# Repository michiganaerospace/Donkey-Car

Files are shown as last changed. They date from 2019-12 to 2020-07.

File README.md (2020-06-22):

# Donkey-Car
The Donkey Car is a remote/self driving RC car project which runs on a Raspberry Pi. We have created some documentation (Donkey RC Car Setup.docx) on how to assemble the Donkey Car that needs to be completed. In this github there is a group of solidworks/stl files that can be used to 3d print parts required to make the Donkey Car. The donkey car docs file has a link to a website with extensive documentation on the Donkey Car. There is a large ammount of additional info at http://docs.donkeycar.com/ , so check it out.
 


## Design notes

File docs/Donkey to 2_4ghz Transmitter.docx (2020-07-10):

## Donkey Car: Pi to 2.4 G RC Transmitter

## To switch from using the Logitech controllers and the Raspberry Pi to using the 2.4 G RC Transmitter (given in the package) use the following steps:

## 1) Make sure the car is off (bottom battery unplugged)

## 2) Unplug the wires from the motor controller and plug them into the receiver near the bottom of the car as shown.

## = steering cable – from channel 0 to channel 2

## = throttle cable – from channel 1 to channel 1

Receiver

Motor Controller

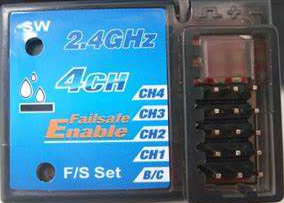
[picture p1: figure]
See the source image
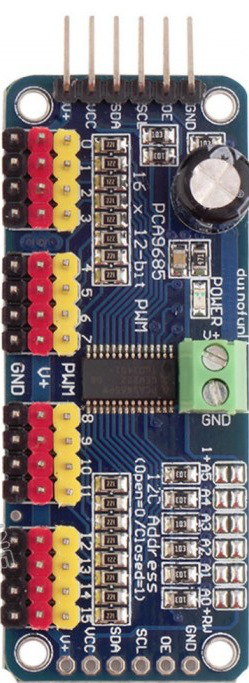
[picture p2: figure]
See the source image
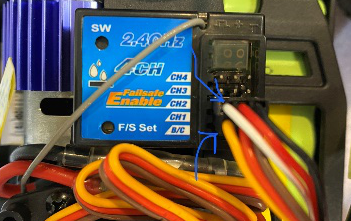
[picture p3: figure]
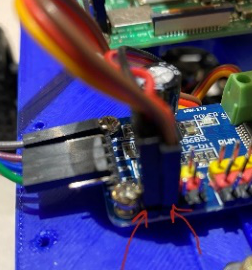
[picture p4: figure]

## 3) Plug the bottom battery pack back in and lights should come on on both the ESC and the receiver. Then take the controller for that designated car and open the top panel to access the on/off switch. Turn it on and you’re ready to go

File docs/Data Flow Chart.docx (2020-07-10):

Data-Flow Diagrams for RC Mode – Pi

During setup

Driver uses PuTTY/Terminal/App to SSH into the Raspberry Pi

Driver uses the RPi terminal to execute the drive command

The drive command enables a web browser that will allow the user to control certain settings of the car and see through the camera

During Driving

Pi receives that signal and sends it through the motor controller, which results in the vehicle driving!

Nano-receiver sends that signal to the laptop through USB port

Controller sends that joystick signal to its respective nano-receiver

Driver moves the joystick

Laptop sends that signal through to the SSH session controlling the Pi and to the web browser

During Training

Driver drives around track, collecting data in the form of photos and values that are put into a folder, or “tub”

With a “drive model” command, the car begins driving, using the model as a reference for how it should respond to the environment or “track”

This “model” is transferred back to the Pi via USB or SSH commands

With a “train” command, the laptop takes and analyzes the data to create a model of how the car should run based on your movements

The “tub” of data is transferred from the Pi to the laptop via Filezilla, USB memory stick, or SSH commands

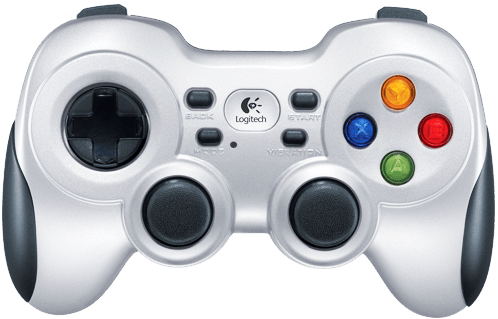
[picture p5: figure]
See the source image
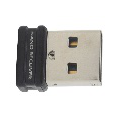
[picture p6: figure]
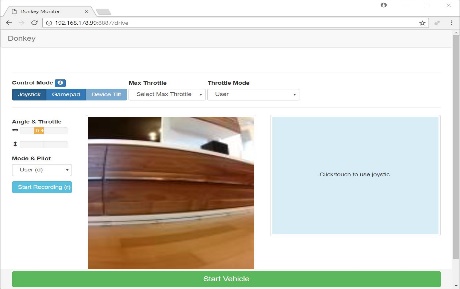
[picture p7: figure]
See the source image
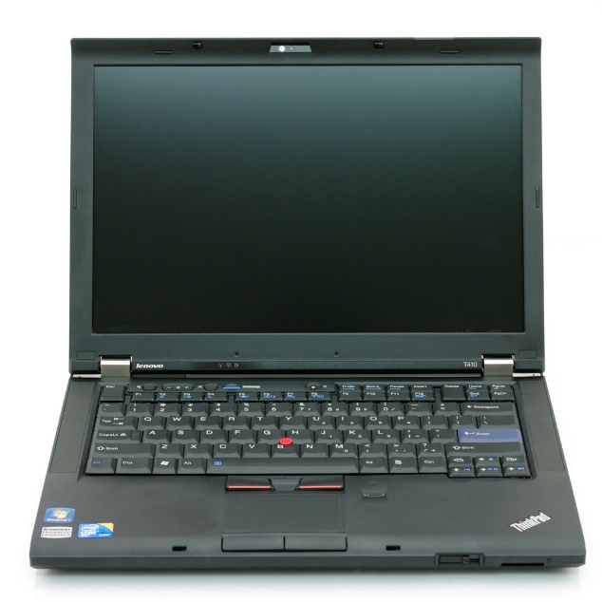
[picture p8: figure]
See the source image
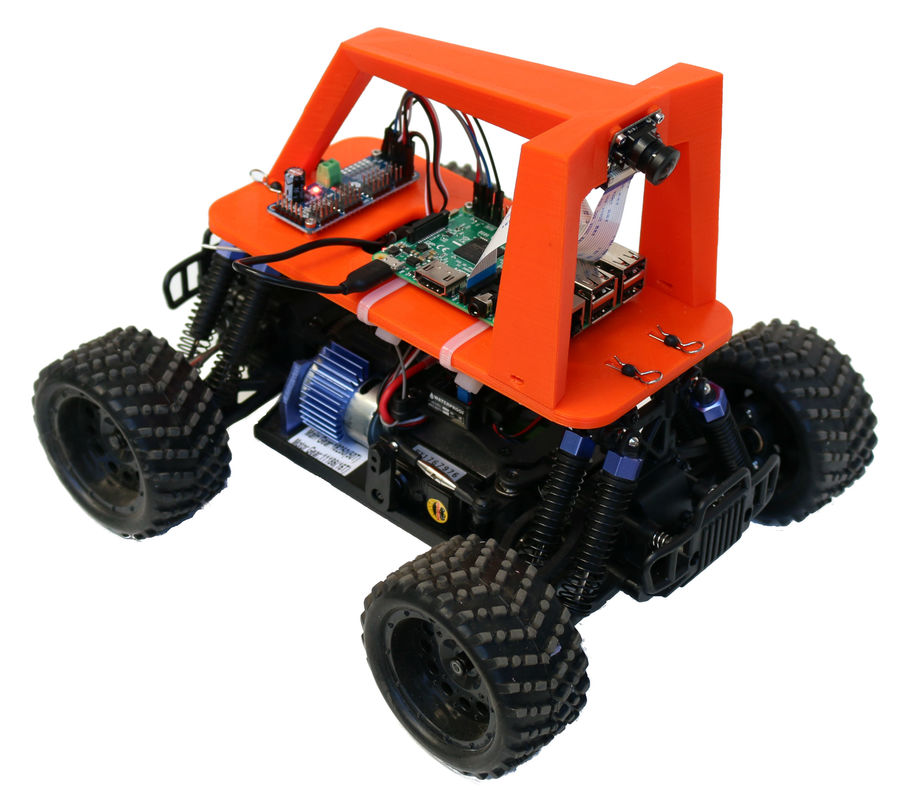
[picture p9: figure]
See the source image
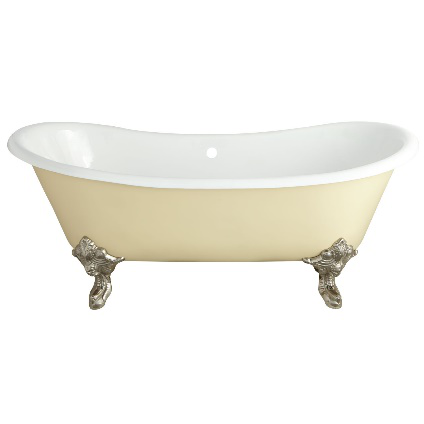
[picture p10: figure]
See the source image
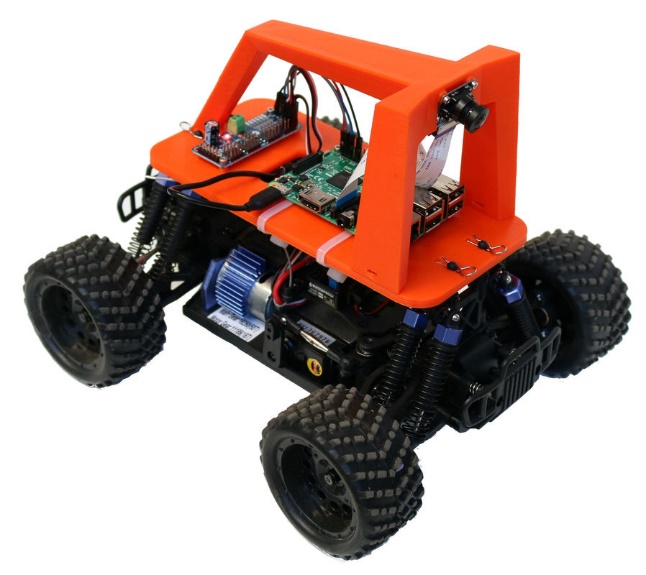
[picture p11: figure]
See the source image
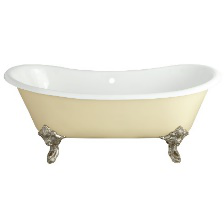
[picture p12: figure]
See the source image
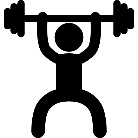
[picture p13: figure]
See the source image
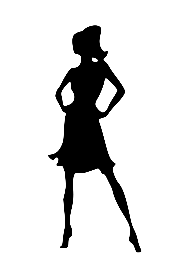
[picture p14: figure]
See the source image
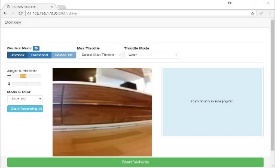
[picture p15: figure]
See the source image
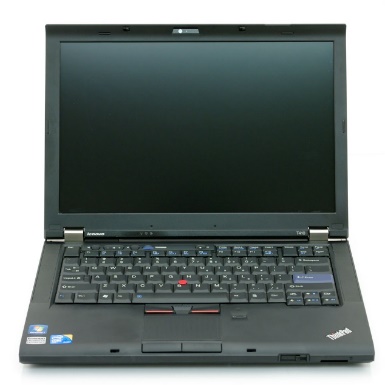
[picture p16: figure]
See the source image

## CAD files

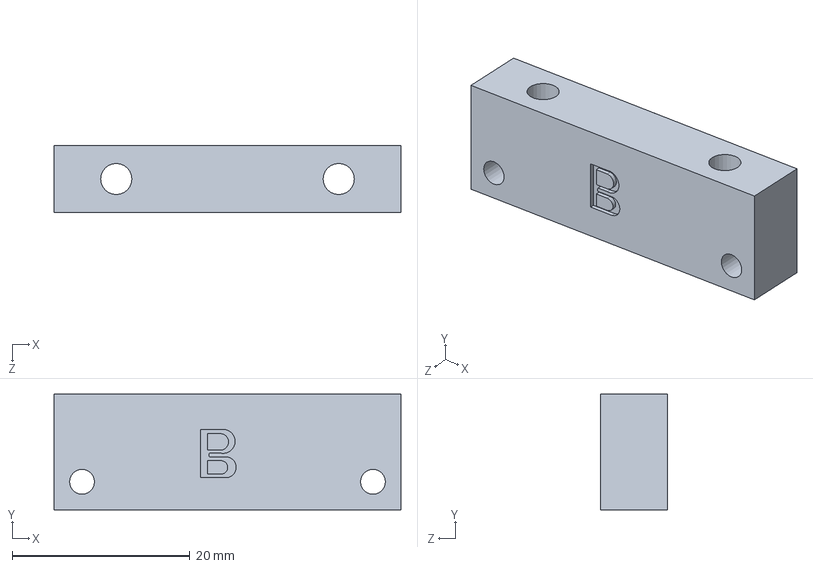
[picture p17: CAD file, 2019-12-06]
3d parts/new back adapter.SLDPRT
39.0 x 13.0 x 7.50 mm

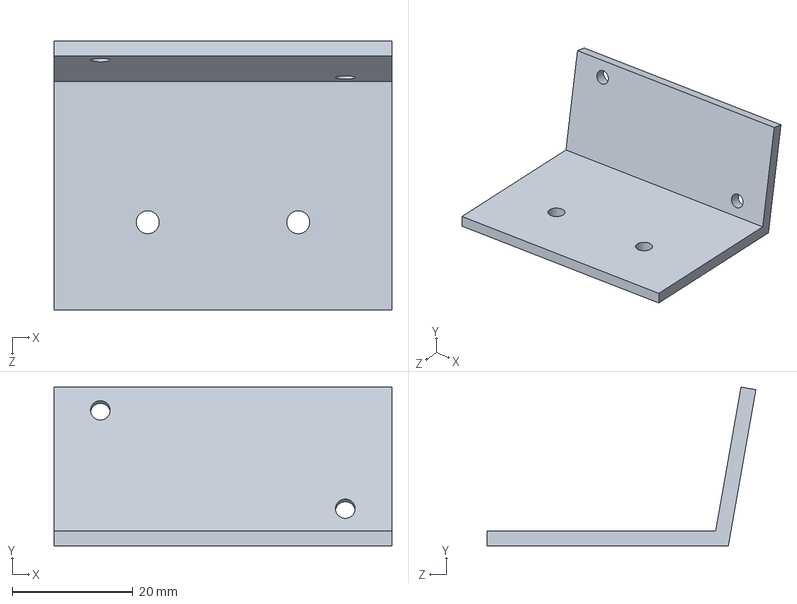
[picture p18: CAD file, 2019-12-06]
3d parts/ping sensor mount v5.SLDPRT
55.9 x 26.3 x 44.4 mm

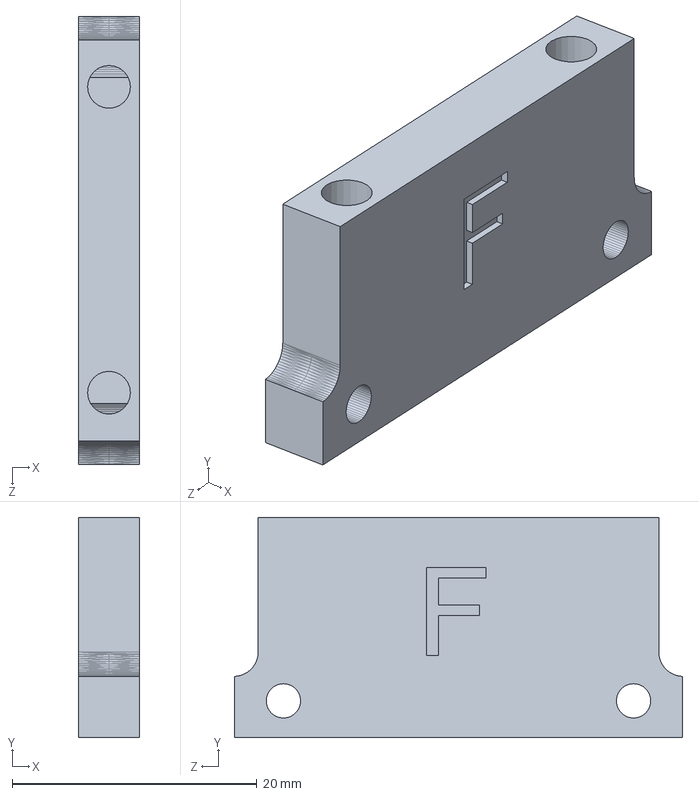
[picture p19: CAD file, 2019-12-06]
3d parts/new front NEW.SLDPRT
5.00 x 18.0 x 36.6 mm

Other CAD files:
3d parts/new back adapter.STL
3d parts/new front NEW.STL

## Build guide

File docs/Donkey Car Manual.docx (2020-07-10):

## Donkey Car Manual

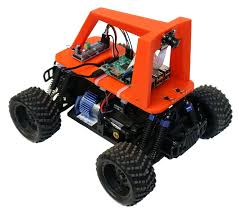
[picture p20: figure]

SD Card Formatting, Powering Up, Wi-Fi Setup……..…………. 2

Connecting to Pi……………………………………………………………….. 2

Driving…………………………………………………………………………….. 3

Training…………………………………………………………………………… 5

Part List……………………………………………………………………………. 8

Printing Parts……………………………………………………………………. 9

Software Install………………………………………………………………… 9

Creating the Car App………………………………………………………… 12

Calibration……………………………………………………………………….. 13

About: Raspbian is the Raspberry Pi Operating System and Balena Etcher is an SD card formatter

# SD Card Formatting

## On a PC, download the latest version of Raspbian, as well as Balena Etcher. Select the Raspbian image and your SD card. Click ‘flash’ to start formatting the SD card. Once the card is formatted, you can slide it into the small SD card slot on the underside of the Raspberry Pi (located at the front).

# Powering up the Donkey Car

To turn on the donkey car you will need two batteries. One is a Ni-MH battery that fits into the bottom slot of the donkey car and has some pins that hold it in. There is a small connector right by the slot that the Ni-MH battery will plug into. In order to power the Pi, there is a Li-Po battery pack which will plug into the Pi thru a USB to micro USB cable. Once you have these two batteries plugged in the donkey car will be ready to roll or setup.

# Setup the Wi-Fi Connection for Pi

To setup Wi-Fi access to the donkey car you will want to power up the Pi on the vehicle. Connect the Pi to a monitor thru the HDMI port on the Pi and plug in a USB mouse and keyboard. Click on the Wi-Fi icon in the top right corner of the Raspberry Pi screen. Select your network and put in the password if necessary

About: The Raspberry Pi is a microcomputer with many different capabilities and applications

# Connecting to the Pi

About: SSH (Secure Shell) is a way to access another computer over a network

## If you followed the above instructions to add Wi-Fi access, your Pi should now be connected to your Wi-Fi network. Now you need to find its IP address so you can connect to it via SSH.

To find the IP address, you will want to plug in an HDMI monitor and USB keyboard/mouse into the Pi, if it isn’t already. Boot it. Login with:

About: An IP address is a string of numbers that are used to identify individual computers and devices

- Username: pi
- Password: 1234

Then try the command in the Pi terminal:

About: A terminal (aka console, command line) is an application in which the user can execute commands directly

ifconfig wlan0

## If this has a valid IPv4 address, 4 groups of numbers separated by dots, then you can try that with your SSH command. If you don't see anything like that, then your Wi-Fi config might have a mistake. You can try to fix with:

Tip: You can also use the Network Analyzer app on your phone to find the IP address of the Pi on the network

sudo nano /etc/wpa_supplicant/wpa_supplicant.conf

In the Pi terminal, type:

ping raspberrypi.local or ping pi-<your car number>.local

Hopefully, one of those methods worked and you have the IP address. On Mac and Linux, you can open Terminal. On Windows, use PuTTY, or on Windows 10 you may have SSH via the command prompt.

Tip: On most computers, you will want to use the PuTTY app to SSH. See the Quick Start Guide for more details on SSH’ing with PuTTY.

If you have a command prompt, you can try:

ssh pi@raspberrypi.local

or ssh pi@<your pi ip address>

About: PuTTY is an open source software that enables users to use different network protocols, such as SSH.

# Drive your car

If you are not already, please SSH into your vehicle (http://docs.donkeycar.com/guide/robot_sbc/setup_raspberry_pi/), then open your car's folder and start your car. Type the following:

python ~/mycar/manage.py drive

This script will start the drive loop in your car, which includes a feature that enables you to use a web controller. It can be accessed on a computer or any electronic device that has access to the internet. You can control your car from a web browser at the URL: <your car's hostname>:8887

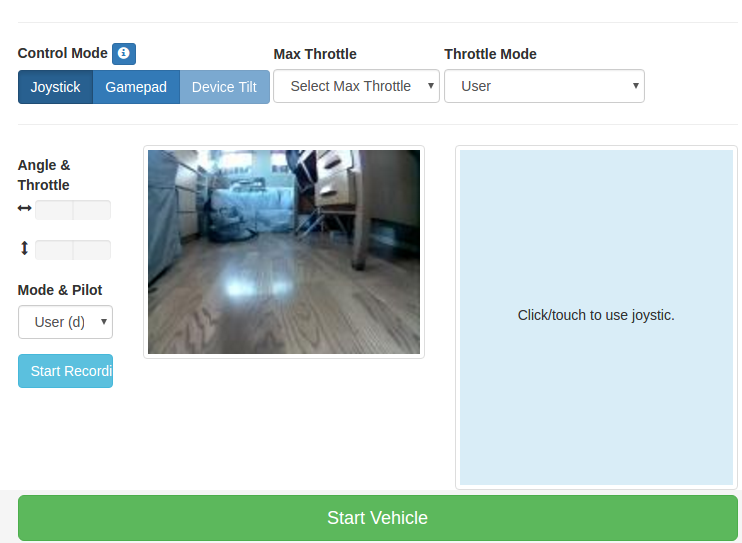
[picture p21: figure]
drive UI

This is what the web controller application should look like:

Tip: Make sure to use Google Chrome or Safari; Microsoft Edge often does not display the camera feed correctly

## Driving with Web Controller

In the browser, there are a couple options for driving:

a) Joystick – This is referring to the blue square to the right of the camera feed. It can be used as a touchpad, but beware of its sensitivity.
b) Gamepad – This is what we will primarily use, since the gamepad option allows you to use a gaming controller, such as the Logitech F710.
c) Device Tilt – The idea behind this is being able to use a device like a phone and tilt from side to side, however this is not a very reliable method.

### Features

- Recording - Press Start Recording to start recording images, steering angles and throttle values.
- Throttle mode - Option to set the throttle as constant. This is used in races if you have a pilot that will steer but doesn't control throttle.
- Mode & Pilot - Choose this if the pilot should control the angle and/or throttle. When we want to autonomously drive, we will switch this option to “Local Pilot” instead of “User”
- Max throttle - Limits the maximum throttle. This can help reduce the sensitivity of the throttle, since the cars tend to be very fast.

### Keyboard Shortcuts (if using keyboard, put into Gamepad mode)

- space : stop car and stop recording
- r : toggle recording
- i : increase throttle
- k : decrease throttle
- j : turn left
- l : turn right

## Driving with Physical Joystick Controller

Since we will be using the Logitech F710 controller, plug the USB nano receiver into your laptop, and open the web controller. Select the ‘Gamepad’ option, press the start button on the controller (may have to click mode too), and start driving. Make sure the slider on the back of the controller is set to ‘X’.

# Training Autopilot

## Collect Data

1. Practice driving around the track a couple times.
2. When you're confident you can drive 10 laps without mistake, restart the python mange.py process to create a new tub session. Press Start Recording if using web controller. The joystick will auto record with any non-zero throttle.
3. If you crash or run off the track press Stop Car immediately to stop recording.
4. After you've collected 10-20 laps of good data (5-20k images) you can stop your car with Ctrl-c in the SSH session for your car.
5. The data you've collected is in the ‘data’ folder in the most recent tub folder.

## Transfer Data

Since the Raspberry Pi is not very powerful, we need to transfer the data to a personal computer, such as a laptop, to train. Transferring can be done two ways: manual with a flash drive, or by using SSH. We have found manual to work better, but rsync is always available.

Manual Version: Plug a monitor and keyboard into the pi, then use a flash drive to copy the tub data from the Pi’s ‘data’ folder to the drive, then from the drive to the host PC’s ‘data’ folder

SSH Version: In a new SSH terminal session on your host PC use rsync to copy your cars folder from the Raspberry Pi. You can transfer the data by typing into the current SSH session terminal:

## rsync -r pi@<your_pi_ip_address>:~/mycar/data/ ~/mycar/data/

or

## rsync -rv --show-progress --partial pi@<your_pi_ip_address>:~/mycar/data/ ~/mycar/data/

## Training Data

Manual Version

## 1. After copying the data, open the Anaconda terminal

## Make sure anaconda and donkey software is downloaded on the PC

## 2. In the Anaconda terminal, type conda activate donkey followed by python ~/mycar/manage.py train -–tub<your tub> --model ~/mycar/models/Pilot1.h5

## May have to specify no tub by using python ~/mycar/manage.py train -–model ./mycar/models/pilot.h5 if you get the “Usage:” error; just make sure that tub is the only one in the folder

## Make sure to check your tubs since it can be picky about your tub location

## 3. It will train (may take 10-30 minutes); once done, copy the model file back to USB and to the pi’s ‘models’ folder – then use python ~/mycar/manage.py drive –-model ~/mycar/models/Pilot1.h5

## 4. In the web browser, make sure ‘Local pilot’ is selected and it should start driving itself.

## 5. Make sure whatever battery you train with, you use during autonomous

## SSH Version

## 1. Once transferred, train the data by typing python ~/mycar/manage.py train --tub <tub folder names comma separated> --model ./models/mypilot.h5 into the current SSH session terminal

## 2. Copy data back to car by typing rsync -rv --show-progress --partial ~/mycar/models/ pi@<your_ip_address>:~/mycar/models/

## 3. Then you can start driving by typing python ~/mycar/manage.py drive --model ~/mycar/models/mypilot.h5

# Donkey Car Parts List

To build the donkey car you will need the following parts:

1. Exceed Racing Desert Short Course Truck 1/16 Scale Ready to Run 2.4ghz (AA Blue)

https://www.amazon.com/Exceed-Racing-Desert-Course-2-4ghz/dp/9269802086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

2. Element14 Raspberry Pi 3 B+ Motherboard https://www.amazon.com/ELEMENT-Element14-Raspberry-Pi-Motherboard/dp/B07BDR5PDW?tag=donkeycar-20
3. HiLetgo 2pcs PCA9685 16 Channel 12-Bit PWM Servo Motor Driver IIC Module for Arduino Robot

https://www.amazon.com/HiLetgo-PCA9685-Channel-12-Bit-Arduino/dp/B07BRS249H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

4. SainSmart Wide Angle Fish-Eye Camera Lenses for Raspberry Pi Arduino

https://www.amazon.com/gp/product/B00N1YJKFS?tag=donkeycar-20

5. M3x10 screws https://www.amazon.com/Screws-Mushroom-Phillips-Self-Tapping-Electronic/dp/B07NQCG6JP?tag=donkeycar-20
6. M2x6 screws https://www.amazon.com/uxcell-Stainless-Phillips-Tapping-Screws/dp/B01KXTSW6Q?tag=donkeycar-20
7. 32GB Micro SD Card https://www.amazon.com/dp/B06XWMQ81P/ref=twister_B07V2PRSXC?_encoding=UTF8&psc=1

# 8. Power Bank 10000mQSah,TONV Portable External Cell Phone Li-Polymer Battery’s 2 Input and 2 Output

https://www.amazon.com/10000mah-TONV-Portable-Li-Polymer-Compatible/dp/B078TFHXVY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

Or

https://www.amazon.com/10000mAh-External-Portable-Compatible-Electric/dp/B07H87HKKM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

9. Vibration-Damping Sandwich Mount https://www.mcmaster.com/5822k4

# 3-D Printing

About: GitHub is an open-source repository for code and other documents, like a cloud

1. Download the 3-D print files for the Donkey Car located on the GitHub https://github.com/michiganaerospace
2. You will need to print the top and bottom Donkey body, the back and front adapter, and the ping sensor mount (optional, only if actually using ping sensor)
3. Put the STL files into the slicer of your choice (preferably Slic3r)
4. Print all the parts of the donkey car
5. Remove/clean any residue from the 3d prints
6. Assemble (http://docs.donkeycar.com/guide/build_hardware/)

# Install Software on Host PC

About: Anaconda is an open source distribution of the Python programming language

1. Install miniconda Python 3.7 64 bit (https://conda.io/miniconda.html).
2. Open the Anaconda prompt window via Start Menu | Anaconda Prompt
3. Type git. If the command is not found, then install Git (https://git-scm.com/download/win) 64 bit
4. Install Notepad++

About: Git allows us to access and use the latest code from a variety of repositories

5. Install PuTTY 64 bit
6. Install Google Chrome

In the Anaconda prompt window:

- Make a directory you would like to use as the head of your projects and go to it

mkdir projects

cd projects

- Get the latest donkey software from GitHub

git clone https://github.com/autorope/donkeycar

cd donkeycar

git checkout master

- If this is not your first install, update Conda and remove old donkey software

conda update -n base -c defaults conda

conda env remove -n donkey

- Create the Python Anaconda environment

conda env create -f install\envs\windows.yml

conda activate donkey

pip install -e .[pc]

- Create your local working directory:

donkey createcar --path ~/mycar

Note: After closing the Anaconda Prompt, when you open it again, you will need to type conda activate donkey to re-enable the mappings to donkey specific Python libraries

# Install Software on Donkey Car

If you haven’t already done so:

1. Plug Raspberry Pi into an HDMI monitor, power supply, USB keyboard, and USB mouse.
2. Connect to a Wi-Fi source

Start the software installation by opening the Pi terminal and typing the specified code:

- Updating and upgrading the Pi’s current software

Fun Fact: ‘apt’ stands for ‘advanced package tool’; apt-get is used to install, remove, and perform operations on installed software packages

Fun Fact: ‘sudo’ stands for ‘superuser do’

sudo apt update

sudo apt-get upgrade

1. Changing Raspberry Pi configuration

sudo raspi-config

- Change default password to 1234
- Enable interfacing options – I2C
- Enable interfacing options – Camera
- Enable interfacing options – SSH
- Advanced Options – Expand filesystem
- Hit enter then reboot
2. Install dependencies

Type the following code or copy and paste from: http://docs.donkeycar.com/guide/robot_sbc/setup_raspberry_pi/#step-5-connecting-to-the-pi

sudo apt-get install build-essential python3 python3-dev python3-pip python3-virtualenv python3-numpy python3-picamera python3-pandas python3-rpi.gpio i2c-tools avahi-utils joystick libopenjp2-7-dev libtiff5-dev gfortran libatlas-base-dev libopenblas-dev libhdf5-serial-dev git ntp

3. Setup virtual environment

Type the following code or copy and paste from: http://docs.donkeycar.com/guide/robot_sbc/setup_raspberry_pi/#step-5-connecting-to-the-pi

python3 -m virtualenv -p python3 env --system-site-packages

echo "source env/bin/activate" >> ~/.bashrc

source ~/.bashrc

4. Install Donkey Car Python code

Type the following code or copy and paste from: http://docs.donkeycar.com/guide/robot_sbc/setup_raspberry_pi/#step-5-connecting-to-the-pi

- Make a directory you would like to be head of your projects, and go to it

mkdir projects

cd projects

- Get latest Donkey Car from GitHub

git clone https://github.com/autorope/donkeycar

cd donkeycar

git checkout master

pip install -e .[pi]

pip install tensorflow==1.13.1

# Create Car Application

If you’re not already, go into the Pi terminal.

- Type the following to create a set of files to control your car:

donkey createcar --path ~/mycar

- To look at the configuration file in the newly created directory, use the command:

nano myconfig.py

Each line has a comment mark. The commented text shows the default value. When you want to make an edit to overwrite the default, uncomment the line by removing the # and any spaces before the first character of the option.

For example:

# STEERING_LEFT_PWM = 460

becomes

STEERING_LEFT_PWM = 500

About: I²C is a protocol for two-wire interfacing to connect low-speed devices like microcontrollers (like Pi’s)

- Configure I2C

Type the following:

sudo apt-get install i2c-tools

sudo i2cdetect -y 1

The i2cdetect command should show you a grid of addresses as shown below. If this isn’t what shows up, check the wiring on the Pi.

0 1 2 3 4 5 6 7 8 9 a b c d e f

00: -- -- -- -- -- -- -- -- -- -- -- -- --

10: -- -- -- -- -- -- -- -- -- -- -- -- -- -- -- --

20: -- -- -- -- -- -- -- -- -- -- -- -- -- -- -- --

30: -- -- -- -- -- -- -- -- -- -- -- -- -- -- -- --

40: 40 -- -- -- -- -- -- -- -- -- -- -- -- -- -- --

50: -- -- -- -- -- -- -- -- -- -- -- -- -- -- -- --

60: -- -- -- -- -- -- -- -- -- -- -- -- -- -- -- --

70: 70 -- -- -- -- -- -- --

# Calibrate Car

- To edit your configuration file use this code

nano ~/mycar/myconfig.py

## Steering Calibration

Make sure your car is off the ground to prevent a runaway situation.

1. Turn on your car.
2. Find the servo (steering, red/white/black wires) cable on your car and see what channel it's plugged into on the PCA board. It should be 1 or 0.
3. In the Pi terminal, type donkey calibrate --channel <your_steering_channel> --bus=1
4. Enter 360 and you should see the wheels on your car move slightly. If not enter 400 or 300.
5. Next enter values +/- 10 from your starting value to find the PWM setting that makes your car turn all the way left and all the way right. Remember these values.
6. Enter these values in myconfig.py file as STEERING_RIGHT_PWM and STEERING_LEFT_PWM.

## Throttle Calibration

1. Find the cable coming from your ESC (brown/yellow/red wires) and see what channel it goes into on the PCA board. This is your throttle channel.
2. In the Pi terminal, type donkey calibrate --channel <your_throttle_channel> --bus=1
1. Enter 370 when prompted for a PWM value.
2. You should hear your ESC beep, indicating that it's calibrated.
3. Enter 400 and you should see your car’s wheels start to go forward. If not, it’s likely that this is reverse. Try entering 330 instead.
4. Keep trying different values until you've found a reasonable max speed, and remember this PWM value.

Reverse on RC cars is a little tricky because the ESC must receive a reverse pulse, zero pulse, and another reverse pulse to start to go backwards. To calibrate a reverse PWM setting:

5. Enter the reverse value (likely 330), then the zero throttle value (370), then the reverse value again.
6. Enter values +/- 10 of the reverse value to find a reasonable reverse speed. Remember this reverse PWM value.

Now open your myconfig.py file and enter the PWM values for your car into the throttle controller part:

- THROTTLE_FORWARD_PWM = PWM value for full throttle forward
- THROTTLE_STOPPED_PWM = PWM value for zero throttle
- THROTTLE_REVERSE_PWM = PWM value at full reverse throttle

About: PWM stands for pulse width modulation, which is a method of reducing the average power delivered by an electrical signal. This is done by rapidly switching the power supply from off to on, which regulates speed.

Tip: Open two terminal windows, one for the config file, and one for the calibration commands; that way you can put the values in as you get them

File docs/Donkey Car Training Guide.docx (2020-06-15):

## Donkey Car Training Guide

## Collect Data

## 1. Practice driving around the track a couple times.

2. When you're confident you can drive 10 laps without mistake, restart the python manage.py process to create a new tub session. The joystick will auto record with any non-zero throttle, so you should be able to start a new tub by stopping the car and starting it back up again – just make sure you don’t stop while you’re driving or it may start a new session from the point at which you stopped.

## 3. If you crash or run off the track, stop the car immediately and set it back on the track.

## 4. You will have to start a new session every time you crash, so try not to mess up!

## 5. After you've collected 10-20 laps of good data (5-20k images) you can stop your car with Ctrl-c in the SSH session for your car.

## 6. The data you've collected is in the ‘data’ folder in the most recent tub folder.

## Transfer Data

## Since the Raspberry Pi is not very powerful, we need to transfer the data to a PC computer to train. Transferring data can be done by using a flash drive or rsync. We will use a flash drive since it typically has less bugs.

## 1. First, plug the monitor, keyboard, and mouse into the pi. If it is not already powered up, do so now.

## 2. Once you are in the Raspberry Pi OS, go to the File Manager and you can find the most recent data tubs my going to home>pi>mycar>data.

## 3. Plug in a flash drive, and copy the desired tub(s) to the flash drive.

## 4. Eject the flash drive and plug it into the host PC, and copy the tub(s) to the host PC’s data folder.

## Clean Data

## 1. Open an anaconda terminal type and change your working directory to your donkey car data/tub folder. typing in cd data_directory

## 2. Enable the donkey environment by typing in conda activate donkey

## 3. typing in tubclean “name of tub” example tubclean 2020060223-Shackspace/

## 4. open an internet browser and type in localhost:8886 where we can select a tub

## 5. Once tub is selected you can play the video by pressing the play button. If you press it again you can pause. To rewind just press b and to split you press c.

## 6. Once you split data you can give it a check mark to mark it to be removed

## 7. Once the whole tub has been cleaned select the red save and delete checked training Data button. This will save a cleaned version of the tub which will improve training performance.

## Train Data

## 1. On the host PC, type ‘anaconda’ into the search bar and open the anaconda terminal.

## a. If nothing comes up, Anaconda may still have to be downloaded onto the PC.

## 2. In the anaconda terminal, type conda activate donkey followed by python ~/mycar/manage.py train -–tub<your tub> --model ./mycar/models/Pilot1.h5

## a. If you get the “usage” error, you may have to specify no tub by using python ~/mycar/manage.py train -–model ./mycar/models/pilot.h5 –just make sure that your tub is the only one in the folder, or else it will train all the tubs.

## 3. It will train (may take 10-30 minutes) and output a ‘model’ file of the data. Copy the model file back to flash drive and to the pi’s ‘models’ folder.

## 4. You can always change the name of your outputted model by changing “Pilot1” to your choice of model name for your specific application.

## Train Data with other neural network types

## 1. In the anaconda terminal, type conda activate donkey

## 2. Initialize training with the --type=<model_type> tag into the anaconda working directory python ~/mycar/manage.py train -–model ./mycar/models/pilot.h5 --type=linear

## 3. Should see the message “get_model_by_type” model Type is: <model_type>

## Types of Neural networks (More details at https://docs.donkeycar.com/parts/keras/)

## linear

## Default - Usually works well but may fail to learn throttle well

## Categorical

## Breaks up stearing and throttle decisions – very robust

## Latent

## Learns an additional latent vector which can improve steering control

## rnn

## Tough on PI3

## 3d

## Tough on PI3

## Behavior

## Takes more effort to train

## Setting Autopilot speed

## 1. To limit the max velocity for ai pilot set in myconfig.py the variable AI_THROTTLE_MULT to a value of your liking

AI_THROTTLE_MULT = 1.0 # this multiplier will scale every throttle value for all output from NN models

## Drive Car

## 1. In the SSH session or directly from the pi terminal, type python ~/mycar/manage.py drive –-model ~/mycar/models/Pilot1.h5

## 2. Open your web browser, and make sure ‘Local pilot’ is selected; once you do so, it should start driving itself.

## a. Make sure whatever battery you train with, you use during autonomous mode.

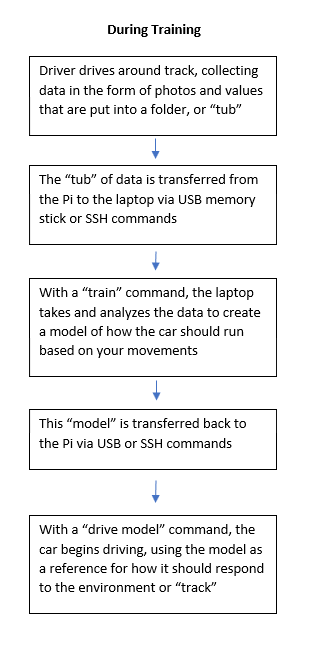
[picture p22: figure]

## b. When you want to stop driving, make sure to exit the browser, use Ctrl+C in the PuTTY terminal to stop the script, and exit the PuTTY window before you power down the pi.

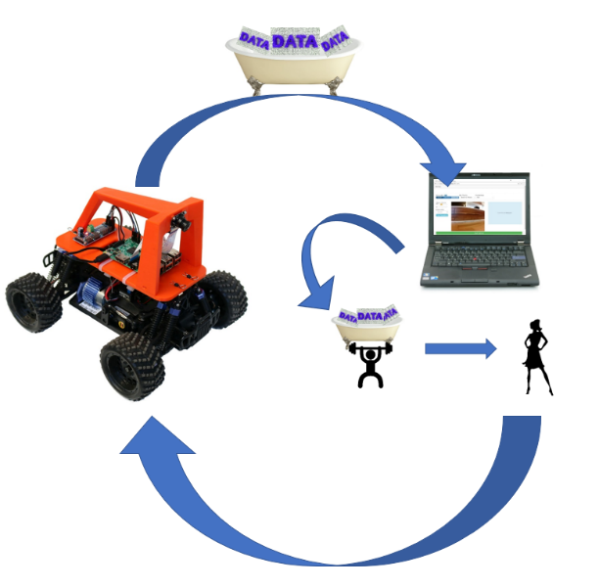
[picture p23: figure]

Visual and graphical representations of training
